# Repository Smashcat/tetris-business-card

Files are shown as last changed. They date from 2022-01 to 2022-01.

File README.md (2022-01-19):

# tetris-business-card
Business card that plays Tetris. Used as xmas toys for clients in 2021!

This repo includes the Eagle design files, production files to use with JLCPCB for full assembly, and firmware to play Tetris and show a couple of animations. All of the parts used here are available on JLC for PCBA, so it should be simple to have them produced and save some soldering! The only thing that might be hard to source at times of the ATMega328pb microcontroller, but it appears from time to time in their stock!

The card is designed for a CR2016 battery. On our cards, we solded a U shaped piece of wire from the pads on each side to hold it in place and keep the card thin enough to go into a wallet. An ideal piece of wire I found was U-shaped sewing pins!

The firmware will compule with Microchip Studio. The card uses pads for tag-connect pogo programmer. I use this cable with an ATMEL ICE programmer, so if you don't have this setup you might want to change this to make it easier to solder wires or something for flashing the firmware. Otherwise maybe flash the firmware on the MCU using an external socket before soldering it on the board.

Although this is kind of specialized for Tetris, I'd be interested in seeing any other games or animations people make!

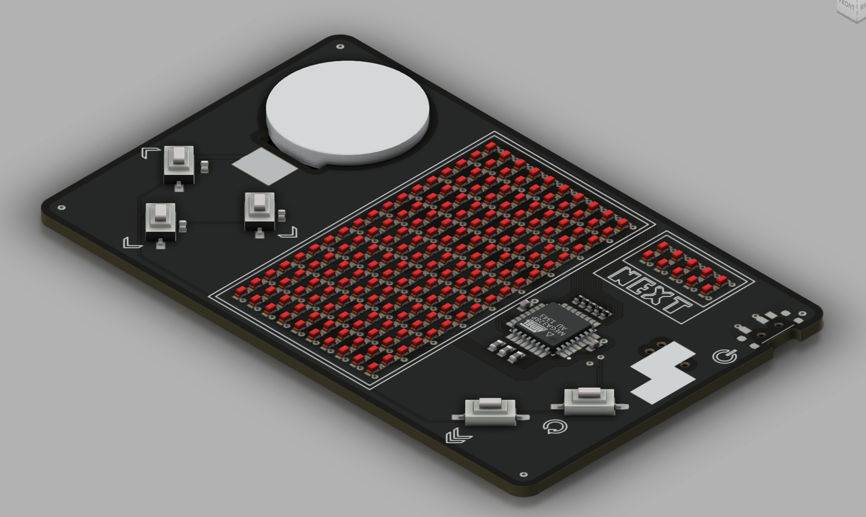
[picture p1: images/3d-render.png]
3D render


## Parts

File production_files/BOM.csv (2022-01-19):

Qty | Designator | Footprint | Comment | LCSC Part # | Description | Device
1 | C2 | C0402 | 0.1uF | C1525 | CAPACITOR, European symbol | C-EUC0402
5 | R5, R9, R10, R12, R14 | R0603 | 10K | C25804 | RESISTOR | 52101-101-REV-A_RC-MASTER-SMD_R_0603MP
1 | C1 | C0402 | 10uf | C15525 | CAPACITOR, European symbol | C-EUC0402
2 | R7, R11 | R0603 | 1K | C21190 | RESISTOR | 52101-101-REV-A_RC-MASTER-SMD_R_0603MP
190 | S_LED1, S_LED2, S_LED3, S_LED4, S_LED5, S_LED6, S_LED7, S_LED8, S_LED9, S_LED10, S_LED11, S_LED12, S_LED13, S_LED14, S_LED15, S_LED16, S_LED17, S_LED18, S_LED19, S_LED20, S_LED21, S_LED22, S_LED23, S_LED24, S_LED25, S_LED26, S_LED27, S_LED28, S_LED29, S_LED30, S_LED31, S_LED32, S_LED33, S_LED34, S_LED35, S_LED36, S_LED37, S_LED38, S_LED39, S_LED40, S_LED41, S_LED42, S_LED43, S_LED44, S_LED45, S_LED46, S_LED47, S_LED48, S_LED49, S_LED50, S_LED51, S_LED52, S_LED53, S_LED54, S_LED55, S_LED56, S_LED57, S_LED58, S_LED59, S_LED60, S_LED61, S_LED62, S_LED63, S_LED64, S_LED65, S_LED66, S_LED67, S_LED68, S_LED69, S_LED70, S_LED71, S_LED72, S_LED73, S_LED74, S_LED75, S_LED76, S_LED77, S_LED78, S_LED79, S_LED80, S_LED81, S_LED82, S_LED83, S_LED84, S_LED85, S_LED86, S_LED87, S_LED88, S_LED89, S_LED90, S_LED91, S_LED92, S_LED93, S_LED94, S_LED95, S_LED96, S_LED97, S_LED98, S_LED99, S_LED100, S_LED101, S_LED102, S_LED103, S_LED104, S_LED105, S_LED106, S_LED107, S_LED108, S_LED109, S_LED110, S_LED111, S_LED112, S_LED113, S_LED114, S_LED115, S_LED116, S_LED117, S_LED118, S_LED119, S_LED120, S_LED121, S_LED122, S_LED123, S_LED124, S_LED125, S_LED126, S_LED127, S_LED128, S_LED129, S_LED130, S_LED131, S_LED132, S_LED133, S_LED134, S_LED135, S_LED136, S_LED137, S_LED138, S_LED139, S_LED140, S_LED141, S_LED142, S_LED143, S_LED144, S_LED145, S_LED146, S_LED147, S_LED148, S_LED149, S_LED150, S_LED151, S_LED152, S_LED153, S_LED154, S_LED155, S_LED156, S_LED157, S_LED158, S_LED159, S_LED160, S_LED1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 | CHIP-LED0603 | 20mA | C375444 | LED | LEDCHIP-LED0603
5 | R1, R2, R3, R8, R15 | R0402 | 470R | C176112 | RESISTOR, European symbol | R-EU_R0402
1 | R6 | R0603 | 4K7 | C23162 | RESISTOR | 52101-101-REV-A_RC-MASTER-SMD_R_0603MP
5 | DOWN, FAST_DROP, LEFT, RIGHT, SPIN | K21107STA4SW06 | K2-1107ST-A4SW-06 | C961737 | Tactile Switches SPST-NO 6.10mm x 3.60mm 2.50mm 50mA @ 12VDC SMD RoHS | K2-1107ST-A4SW-06
1 | S1 | K31296SE1 | K3-1296S-E1 | C431541 | Toggle Switches SMD RoHS | K3-1296S-E1
1 | U1 | MICROCHIP_ATMEGA328PB-AU_0 | MICROCHIP_ATMEGA328PB-AUMICROCHIP_ATMEGA328PB-AU_0_0 | C132230 | ATmega328PB Summary Datasheet | MICROCHIP_ATMEGA328PB-AUMICROCHIP_ATMEGA328PB-AU_0_0

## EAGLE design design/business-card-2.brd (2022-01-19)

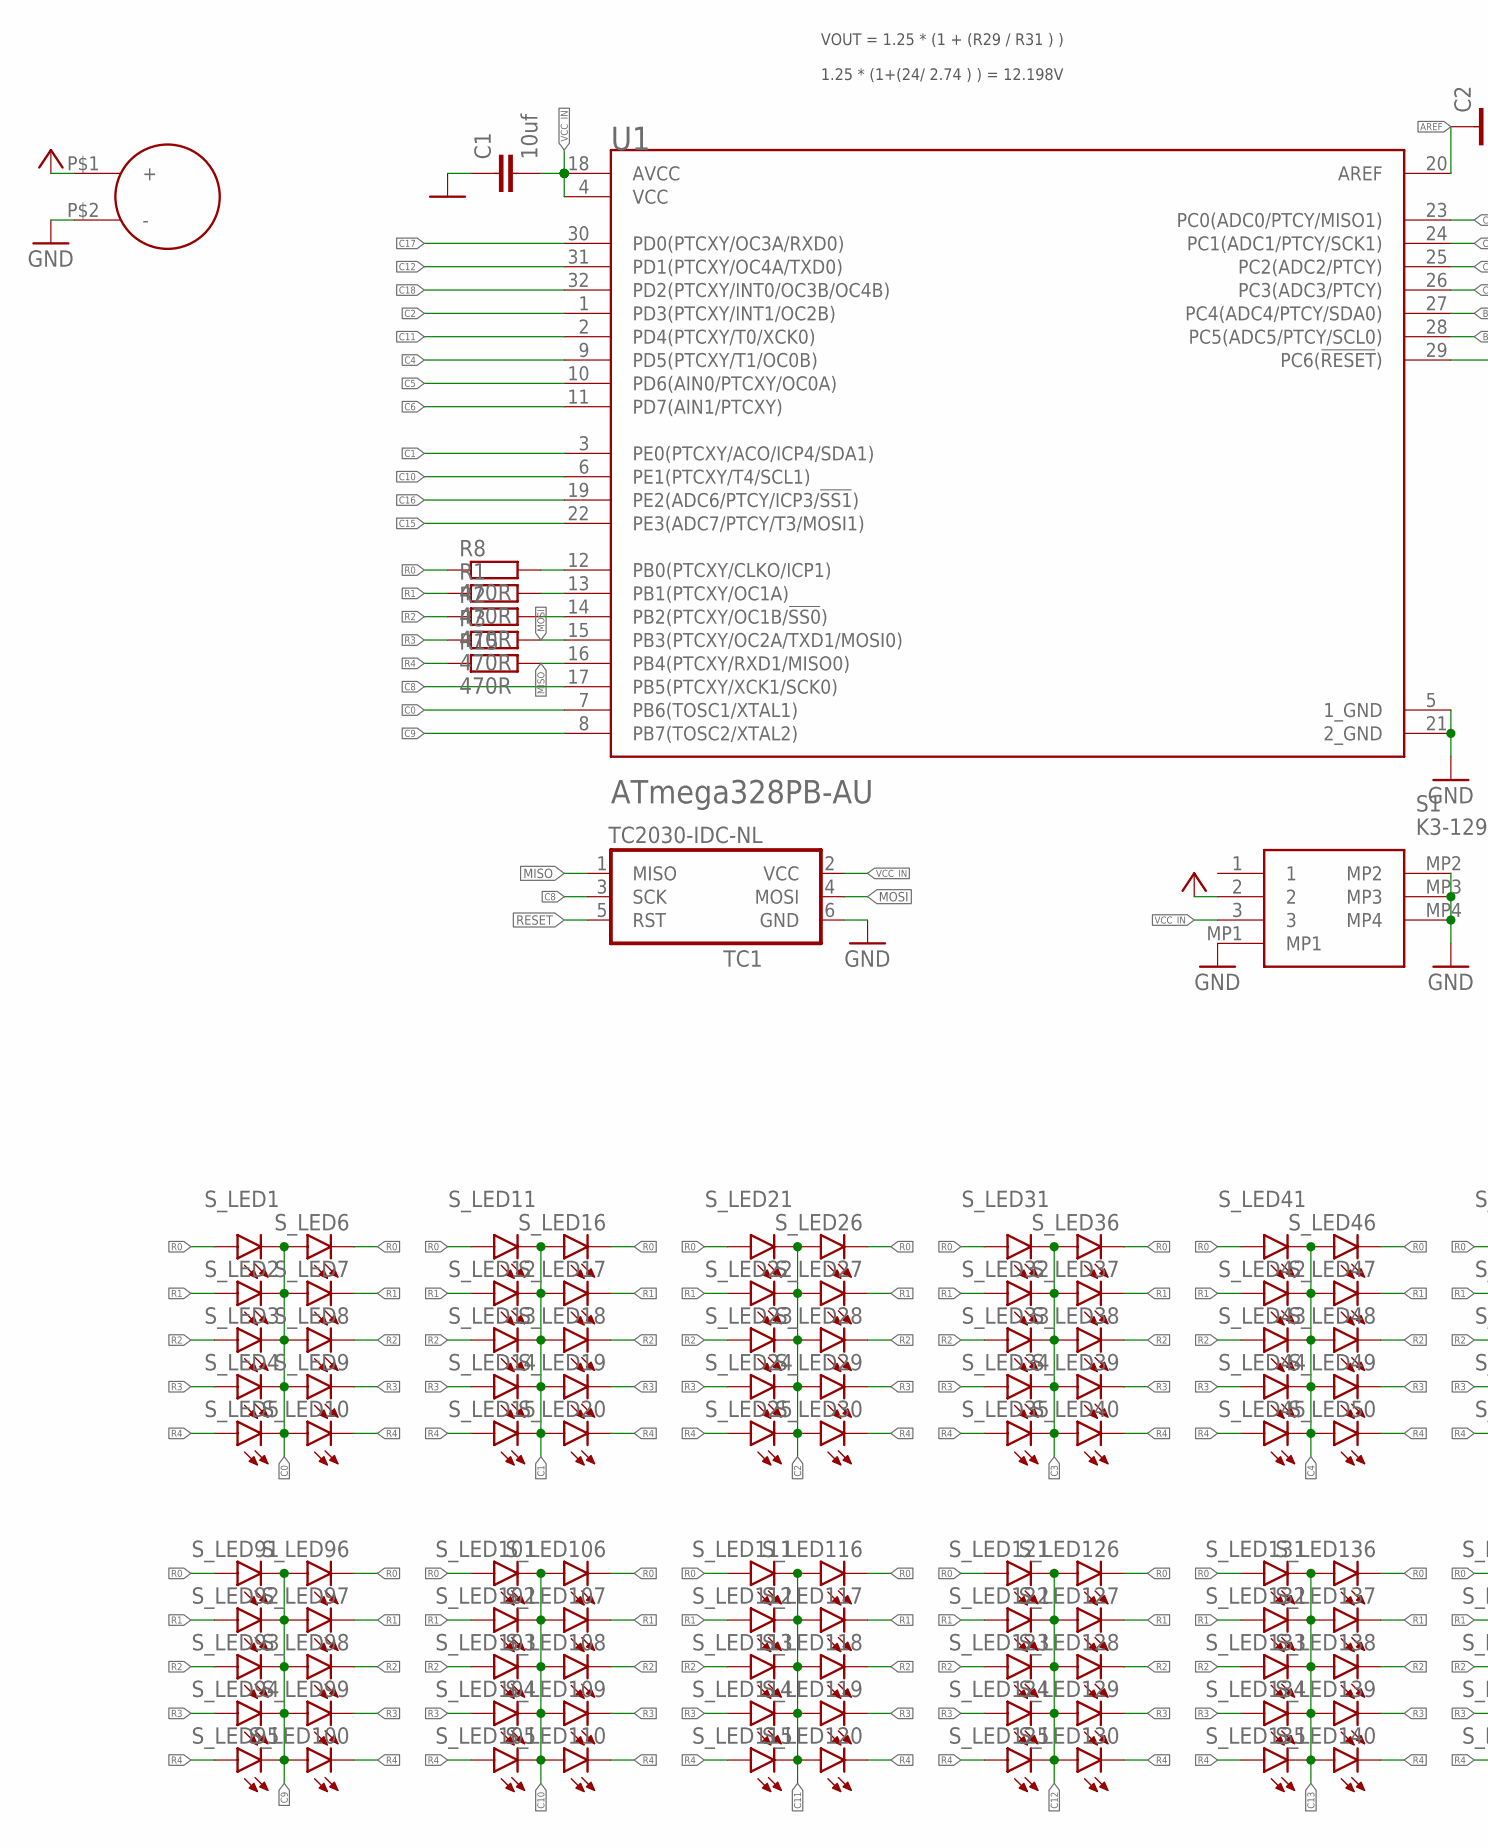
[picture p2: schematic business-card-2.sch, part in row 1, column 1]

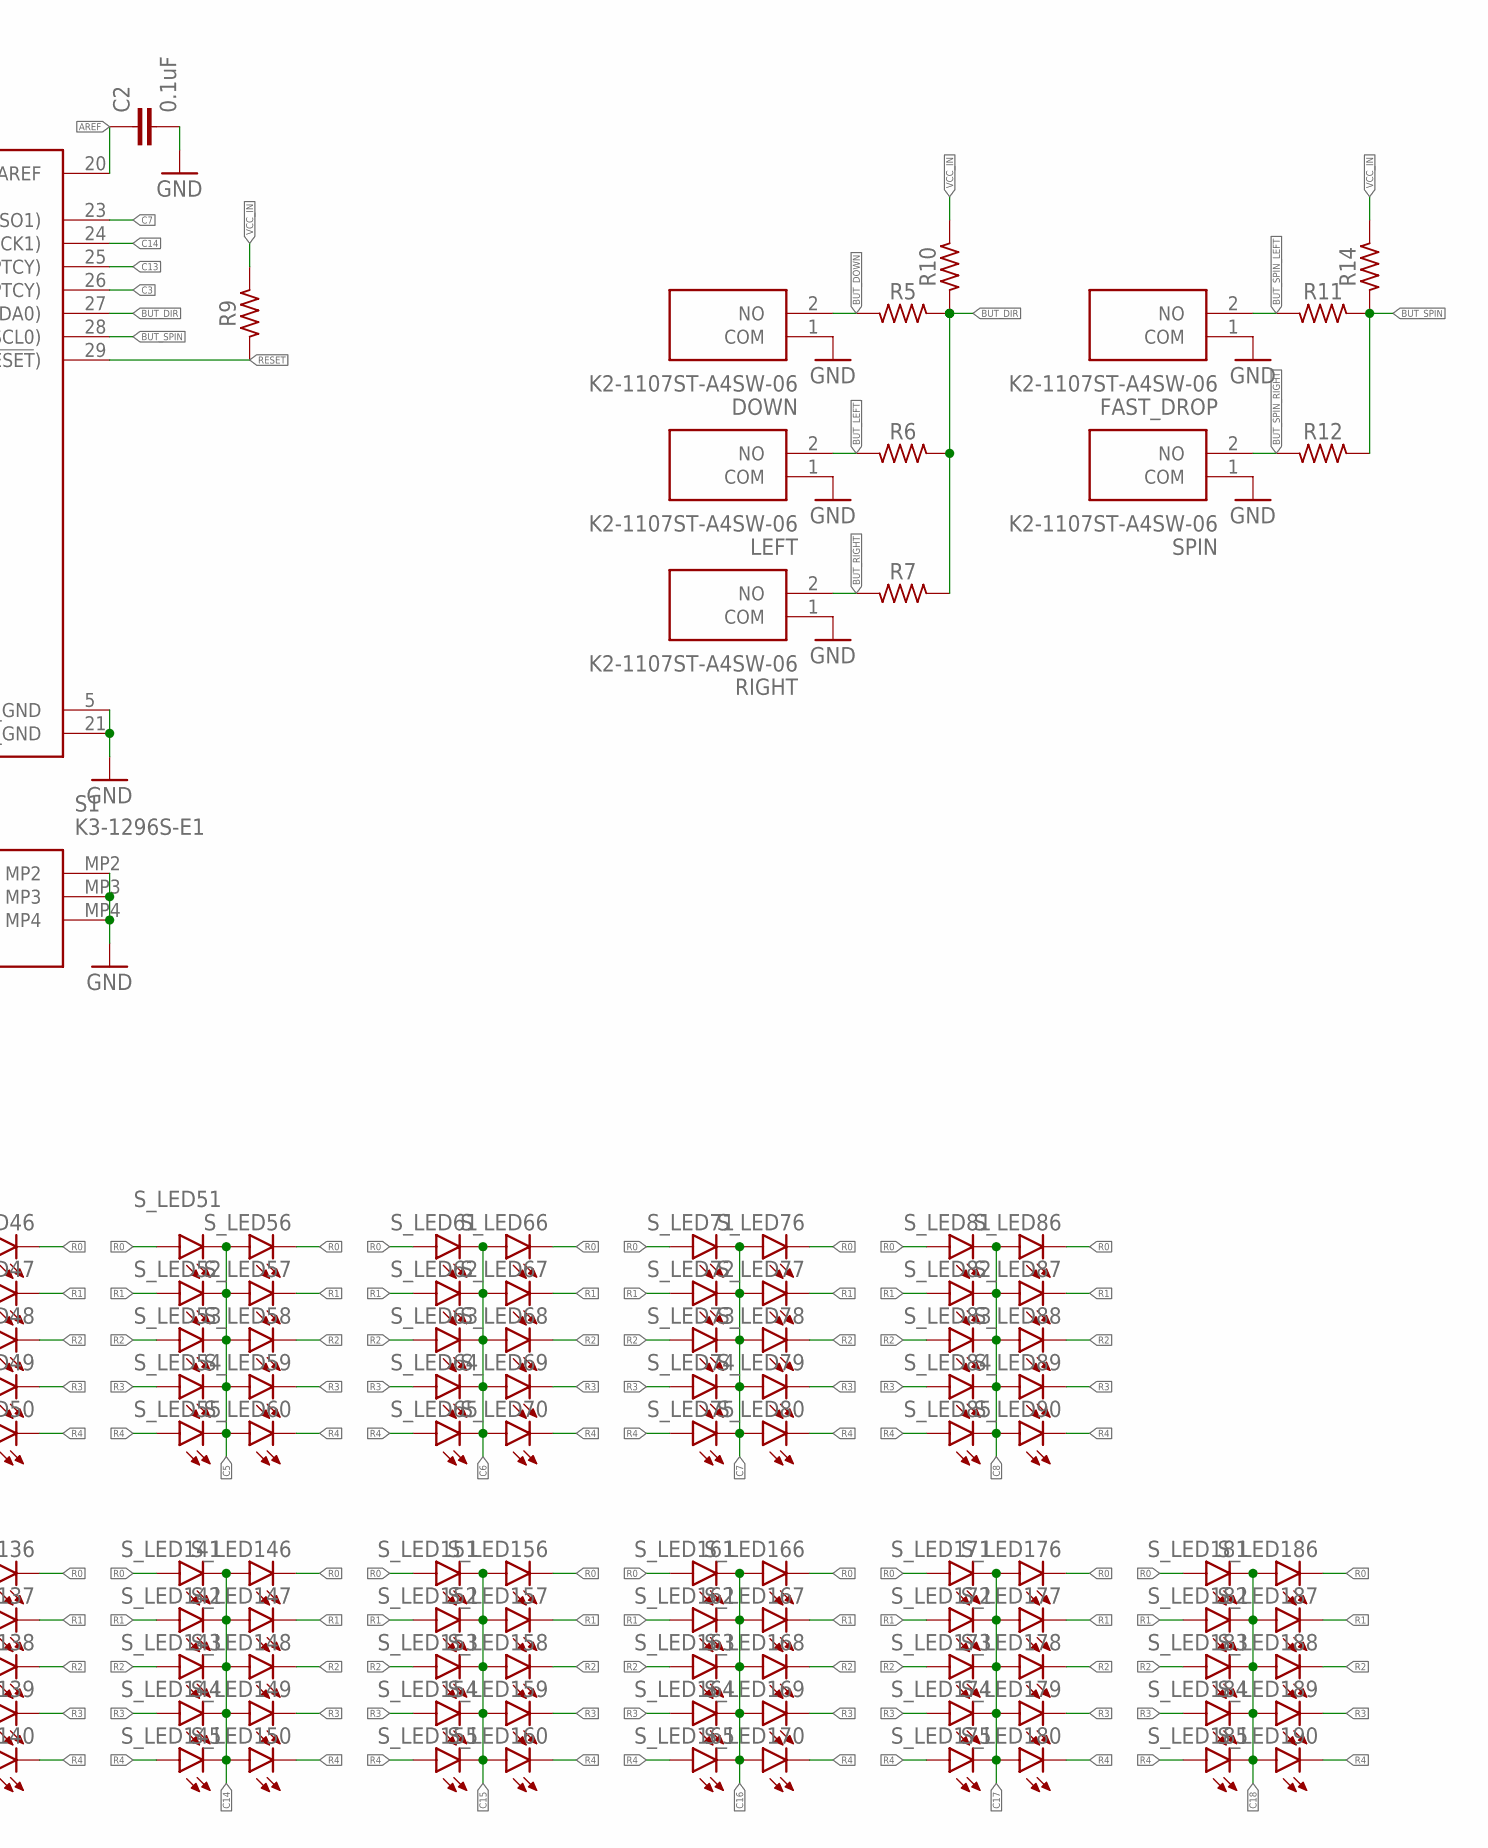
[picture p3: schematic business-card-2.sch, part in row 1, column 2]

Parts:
C1: 10uf; C0402
C2: 0.1uF; C0402
DOWN: K2-1107ST-A4SW-06; K21107STA4SW06
FAST_DROP: K2-1107ST-A4SW-06; K21107STA4SW06
LEFT: K2-1107ST-A4SW-06; K21107STA4SW06
R1, R2, R3, R8, R15: 470R; R0402
R5, R9, R10, R12, R14: 10K; 52101-101-REV-A_RC-MASTER-SMD_R0603MP
R6: 4K7; 52101-101-REV-A_RC-MASTER-SMD_R0603MP
R7, R11: 1K; 52101-101-REV-A_RC-MASTER-SMD_R0603MP
RIGHT: K2-1107ST-A4SW-06; K21107STA4SW06
S1: K3-1296S-E1; K31296SE1
SPIN: K2-1107ST-A4SW-06; K21107STA4SW06
S_LED1, S_LED2, S_LED3, S_LED4, S_LED5, S_LED6, S_LED7, S_LED8, S_LED9, S_LED10, S_LED11, S_LED12, S_LED13, S_LED14, S_LED15, S_LED16, S_LED17, S_LED18, S_LED19, S_LED20, S_LED21, S_LED22, S_LED23, S_LED24, S_LED25, S_LED26, S_LED27, S_LED28, S_LED29, S_LED30, S_LED31, S_LED32, S_LED33, S_LED34, S_LED35, S_LED36, S_LED37, S_LED38, S_LED39, S_LED40, S_LED41, S_LED42, S_LED43, S_LED44, S_LED45, S_LED46, S_LED47, S_LED48, S_LED49, S_LED50, S_LED51, S_LED52, S_LED53, S_LED54, S_LED55, S_LED56, S_LED57, S_LED58, S_LED59, S_LED60, S_LED61, S_LED62, S_LED63, S_LED64, S_LED65, S_LED66, S_LED67, S_LED68, S_LED69, S_LED70, S_LED71, S_LED72, S_LED73, S_LED74, S_LED75, S_LED76, S_LED77, S_LED78, S_LED79, S_LED80, S_LED81, S_LED82, S_LED83, S_LED84, S_LED85, S_LED86, S_LED87, S_LED88, S_LED89, S_LED90, S_LED91, S_LED92, S_LED93, S_LED94, S_LED95, S_LED96, S_LED97, S_LED98, S_LED99, S_LED100, S_LED101, S_LED102, S_LED103, S_LED104, S_LED105, S_LED106, S_LED107, S_LED108, S_LED109, S_LED110, S_LED111, S_LED112, S_LED113, S_LED114, S_LED115, S_LED116, S_LED117, S_LED118, S_LED119, S_LED120, S_LED121, S_LED122, S_LED123, S_LED124, S_LED125, S_LED126, S_LED127, S_LED128, S_LED129, S_LED130, S_LED131, S_LED132, S_LED133, S_LED134, S_LED135, S_LED136, S_LED137, S_LED138, S_LED139, S_LED140, S_LED141, S_LED142, S_LED143, S_LED144, S_LED145, S_LED146, S_LED147, S_LED148, S_LED149, S_LED150, S_LED151, S_LED152, S_LED153, S_LED154, S_LED155, S_LED156, S_LED157, S_LED158, S_LED159, S_LED160, S_LED161, S_LED162, S_LED163, S_LED164, S_LED165, S_LED166, S_LED167, S_LED168, S_LED169, S_LED170, S_LED171, S_LED172, S_LED173, S_LED174, S_LED175, S_LED176, S_LED177, S_LED178, S_LED179, S_LED180, S_LED181, S_LED182, S_LED183, S_LED184, S_LED185, S_LED186, S_LED187, S_LED188, S_LED189, S_LED190: 20mA; CHIP-LED0603
TC1: TC2030-IDC-NL
U1: MICROCHIP_ATMEGA328PB-AUMICROCHIP_ATMEGA328PB-AU_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; MICROCHIP_ATMEGA328PB-AU_0
U$1: THROUGHHOLE-CR2032; THROUGH-HOLE-CR2032

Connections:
AREF: C2.1, U1.20 (AREF)
BUT_DIR: R5.2, R6.2, R7.2, R10.1, U1.27 (PC4(ADC4/PTCY/SDA0))
BUT_DOWN: DOWN.2 (NO), R5.1
BUT_LEFT: LEFT.2 (NO), R6.1
BUT_RIGHT: R7.1, RIGHT.2 (NO)
BUT_SPIN: R11.2, R12.2, R14.1, U1.28 (PC5(ADC5/PTCY/SCL0))
BUT_SPIN_LEFT: FAST_DROP.2 (NO), R11.1
BUT_SPIN_RIGHT: R12.1, SPIN.2 (NO)
C0: S_LED1.C, S_LED2.C, S_LED3.C, S_LED4.C, S_LED5.C, S_LED6.A, S_LED7.A, S_LED8.A, S_LED9.A, S_LED10.A, U1.7 (PB6(TOSC1/XTAL1))
C1: S_LED11.C, S_LED12.C, S_LED13.C, S_LED14.C, S_LED15.C, S_LED16.A, S_LED17.A, S_LED18.A, S_LED19.A, S_LED20.A, U1.3 (PE0(PTCXY/ACO/ICP4/SDA1))
C2: S_LED21.C, S_LED22.C, S_LED23.C, S_LED24.C, S_LED25.C, S_LED26.A, S_LED27.A, S_LED28.A, S_LED29.A, S_LED30.A, U1.1 (PD3(PTCXY/INT1/OC2B))
C3: S_LED31.C, S_LED32.C, S_LED33.C, S_LED34.C, S_LED35.C, S_LED36.A, S_LED37.A, S_LED38.A, S_LED39.A, S_LED40.A, U1.26 (PC3(ADC3/PTCY))
C4: S_LED41.C, S_LED42.C, S_LED43.C, S_LED44.C, S_LED45.C, S_LED46.A, S_LED47.A, S_LED48.A, S_LED49.A, S_LED50.A, U1.9 (PD5(PTCXY/T1/OC0B))
C5: S_LED51.C, S_LED52.C, S_LED53.C, S_LED54.C, S_LED55.C, S_LED56.A, S_LED57.A, S_LED58.A, S_LED59.A, S_LED60.A, U1.10 (PD6(AIN0/PTCXY/OC0A))
C6: S_LED61.C, S_LED62.C, S_LED63.C, S_LED64.C, S_LED65.C, S_LED66.A, S_LED67.A, S_LED68.A, S_LED69.A, S_LED70.A, U1.11 (PD7(AIN1/PTCXY))
C7: S_LED71.C, S_LED72.C, S_LED73.C, S_LED74.C, S_LED75.C, S_LED76.A, S_LED77.A, S_LED78.A, S_LED79.A, S_LED80.A, U1.23 (PC0(ADC0/PTCY/MISO1))
C8: S_LED81.C, S_LED82.C, S_LED83.C, S_LED84.C, S_LED85.C, S_LED86.A, S_LED87.A, S_LED88.A, S_LED89.A, S_LED90.A, TC1.3 (SCK), U1.17 (PB5(PTCXY/XCK1/SCK0))
C9: S_LED91.C, S_LED92.C, S_LED93.C, S_LED94.C, S_LED95.C, S_LED96.A, S_LED97.A, S_LED98.A, S_LED99.A, S_LED100.A, U1.8 (PB7(TOSC2/XTAL2))
C10: S_LED101.C, S_LED102.C, S_LED103.C, S_LED104.C, S_LED105.C, S_LED106.A, S_LED107.A, S_LED108.A, S_LED109.A, S_LED110.A, U1.6 (PE1(PTCXY/T4/SCL1))
C11: S_LED111.C, S_LED112.C, S_LED113.C, S_LED114.C, S_LED115.C, S_LED116.A, S_LED117.A, S_LED118.A, S_LED119.A, S_LED120.A, U1.2 (PD4(PTCXY/T0/XCK0))
C12: S_LED121.C, S_LED122.C, S_LED123.C, S_LED124.C, S_LED125.C, S_LED126.A, S_LED127.A, S_LED128.A, S_LED129.A, S_LED130.A, U1.31 (PD1(PTCXY/OC4A/TXD0))
C13: S_LED131.C, S_LED132.C, S_LED133.C, S_LED134.C, S_LED135.C, S_LED136.A, S_LED137.A, S_LED138.A, S_LED139.A, S_LED140.A, U1.25 (PC2(ADC2/PTCY))
C14: S_LED141.C, S_LED142.C, S_LED143.C, S_LED144.C, S_LED145.C, S_LED146.A, S_LED147.A, S_LED148.A, S_LED149.A, S_LED150.A, U1.24 (PC1(ADC1/PTCY/SCK1))
C15: S_LED151.C, S_LED152.C, S_LED153.C, S_LED154.C, S_LED155.C, S_LED156.A, S_LED157.A, S_LED158.A, S_LED159.A, S_LED160.A, U1.22 (PE3(ADC7/PTCY/T3/MOSI1))
C16: S_LED161.C, S_LED162.C, S_LED163.C, S_LED164.C, S_LED165.C, S_LED166.A, S_LED167.A, S_LED168.A, S_LED169.A, S_LED170.A, U1.19 (PE2(ADC6/PTCY/ICP3/!SS1!))
C17: S_LED171.C, S_LED172.C, S_LED173.C, S_LED174.C, S_LED175.C, S_LED176.A, S_LED177.A, S_LED178.A, S_LED179.A, S_LED180.A, U1.30 (PD0(PTCXY/OC3A/RXD0))
C18: S_LED181.C, S_LED182.C, S_LED183.C, S_LED184.C, S_LED185.C, S_LED186.A, S_LED187.A, S_LED188.A, S_LED189.A, S_LED190.A, U1.32 (PD2(PTCXY/INT0/OC3B/OC4B))
GND: C1.1, C2.2, DOWN.1 (COM), FAST_DROP.1 (COM), LEFT.1 (COM), RIGHT.1 (COM), S1.MP1, S1.MP2, S1.MP3, S1.MP4, SPIN.1 (COM), TC1.6 (GND), U1.5 (1_GND), U1.21 (2_GND), U$1.P$2 (-)
MISO: R15.2, TC1.1 (MISO), U1.16 (PB4(PTCXY/RXD1/MISO0))
MOSI: R3.2, TC1.4 (MOSI), U1.15 (PB3(PTCXY/OC2A/TXD1/MOSI0))
unnamed: R2.2, U1.14 (PB2(PTCXY/OC1B/!SS0!))
unnamed: R8.2, U1.12 (PB0(PTCXY/CLKO/ICP1))
unnamed: R1.2, U1.13 (PB1(PTCXY/OC1A))
R0: R8.1, S_LED1.A, S_LED6.C, S_LED11.A, S_LED16.C, S_LED21.A, S_LED26.C, S_LED31.A, S_LED36.C, S_LED41.A, S_LED46.C, S_LED51.A, S_LED56.C, S_LED61.A, S_LED66.C, S_LED71.A, S_LED76.C, S_LED81.A, S_LED86.C, S_LED91.A, S_LED96.C, S_LED101.A, S_LED106.C, S_LED111.A, S_LED116.C, S_LED121.A, S_LED126.C, S_LED131.A, S_LED136.C, S_LED141.A, S_LED146.C, S_LED151.A, S_LED156.C, S_LED161.A, S_LED166.C, S_LED171.A, S_LED176.C, S_LED181.A, S_LED186.C
R1: R1.1, S_LED2.A, S_LED7.C, S_LED12.A, S_LED17.C, S_LED22.A, S_LED27.C, S_LED32.A, S_LED37.C, S_LED42.A, S_LED47.C, S_LED52.A, S_LED57.C, S_LED62.A, S_LED67.C, S_LED72.A, S_LED77.C, S_LED82.A, S_LED87.C, S_LED92.A, S_LED97.C, S_LED102.A, S_LED107.C, S_LED112.A, S_LED117.C, S_LED122.A, S_LED127.C, S_LED132.A, S_LED137.C, S_LED142.A, S_LED147.C, S_LED152.A, S_LED157.C, S_LED162.A, S_LED167.C, S_LED172.A, S_LED177.C, S_LED182.A, S_LED187.C
R2: R2.1, S_LED3.A, S_LED8.C, S_LED13.A, S_LED18.C, S_LED23.A, S_LED28.C, S_LED33.A, S_LED38.C, S_LED43.A, S_LED48.C, S_LED53.A, S_LED58.C, S_LED63.A, S_LED68.C, S_LED73.A, S_LED78.C, S_LED83.A, S_LED88.C, S_LED93.A, S_LED98.C, S_LED103.A, S_LED108.C, S_LED113.A, S_LED118.C, S_LED123.A, S_LED128.C, S_LED133.A, S_LED138.C, S_LED143.A, S_LED148.C, S_LED153.A, S_LED158.C, S_LED163.A, S_LED168.C, S_LED173.A, S_LED178.C, S_LED183.A, S_LED188.C
R3: R3.1, S_LED4.A, S_LED9.C, S_LED14.A, S_LED19.C, S_LED24.A, S_LED29.C, S_LED34.A, S_LED39.C, S_LED44.A, S_LED49.C, S_LED54.A, S_LED59.C, S_LED64.A, S_LED69.C, S_LED74.A, S_LED79.C, S_LED84.A, S_LED89.C, S_LED94.A, S_LED99.C, S_LED104.A, S_LED109.C, S_LED114.A, S_LED119.C, S_LED124.A, S_LED129.C, S_LED134.A, S_LED139.C, S_LED144.A, S_LED149.C, S_LED154.A, S_LED159.C, S_LED164.A, S_LED169.C, S_LED174.A, S_LED179.C, S_LED184.A, S_LED189.C
R4: R15.1, S_LED5.A, S_LED10.C, S_LED15.A, S_LED20.C, S_LED25.A, S_LED30.C, S_LED35.A, S_LED40.C, S_LED45.A, S_LED50.C, S_LED55.A, S_LED60.C, S_LED65.A, S_LED70.C, S_LED75.A, S_LED80.C, S_LED85.A, S_LED90.C, S_LED95.A, S_LED100.C, S_LED105.A, S_LED110.C, S_LED115.A, S_LED120.C, S_LED125.A, S_LED130.C, S_LED135.A, S_LED140.C, S_LED145.A, S_LED150.C, S_LED155.A, S_LED160.C, S_LED165.A, S_LED170.C, S_LED175.A, S_LED180.C, S_LED185.A, S_LED190.C
RESET: R9.1, TC1.5 (RST), U1.29 (PC6(!RESET!))
VCC: S1.2, U$1.P$1 (+)
VCC_IN: C1.2, R9.2, R10.2, R14.2, S1.3, TC1.2 (VCC), U1.4 (VCC), U1.18 (AVCC)

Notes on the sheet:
VOUT = 1.25 * (1 + (R29 / R31 ) ) 1.25 * (1+(24/ 2.74 ) ) = 12.198V

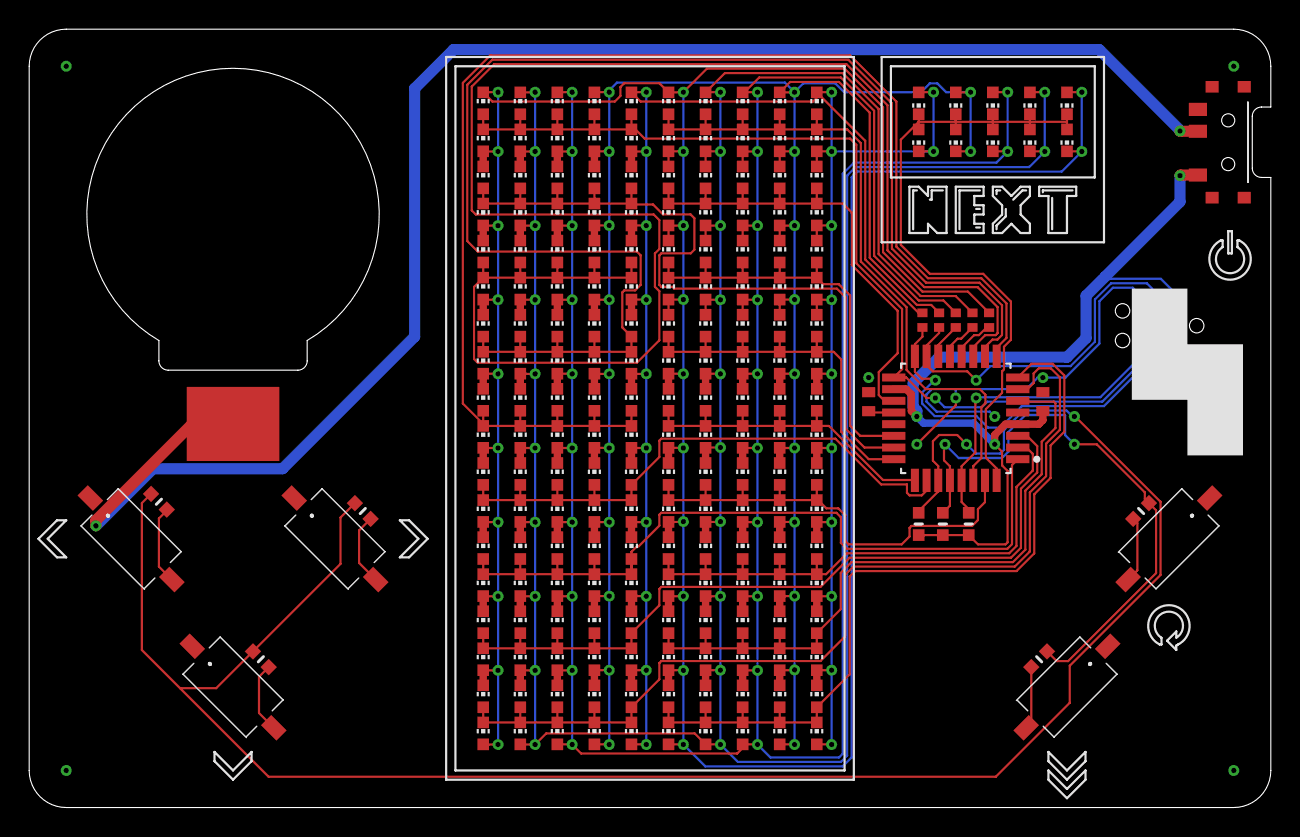
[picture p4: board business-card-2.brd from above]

Board: 2 copper layers, 85.1 x 53.3 mm, 214 parts (1 on the bottom side), 41 nets.

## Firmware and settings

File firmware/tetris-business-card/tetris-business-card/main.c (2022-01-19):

/*
 * tetris-business-card.c
 *
 * Created: 10/09/2021 13:37:38
 * Author : Scott Porter
 */ 

#include "funcs.h"
#include "tetris.h"
#include "maze.h"
#include "life.h"

int main(void)
{
	while(1){
		
		// Version 1 boards had hardware interrupt to wake from sleep. New boards use slide switch.
		#if VER==1
		goToSleep();
		#endif

		setup();
		//testButtons();	// Enable this to just test the input buttons
		#if VER==2
		getButtonState();
		#endif
		//testDisplay();	// enable this to just test the LED matrix
		if(butPressed(BUTTON_LEFT)){
			waitBut();
			spinCog();
			playGameOfLife();
		}
		doMenu();
		playTetris();
		/* Initially was going to have 2 games. But ran out of time!
		uint8_t option=doMenu();
		switch(option){
			case 0:
				playTetris();
				break;
			case 1:
				playMaze();
				break;
			default:
				break;
		}
		*/
		shutdown();
		spinLogo();
	}
}

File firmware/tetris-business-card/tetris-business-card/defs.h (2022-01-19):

/*
 * defs.h
 *
 * Created: 10/09/2021 13:44:23
 *  Author: Scott Porter
 */ 


#ifndef DEFS_H_
#define DEFS_H_

// Version 1 boards used a wake button, version 2 uses a slide switch for power-on/off
#define VER					2

// If in test mode, preload game grid ready for a tetris
#define TEST_MODE			0

// Defines used to switch display between fast and slow modes
#define VIDEO_MODE_FAST		1
#define VIDEO_MODE_SLOW		2

// Number of bytes per video frame (3 brightness levels per pixel)
#define BYTES_PER_FRAME		45

// Speed at which to update the "next piece" display. Lower=faster
#define NP_SPEED			2

// The game speeds up every 2 rows cleared
// Initial game speed - higher = slower
#define INITIAL_GAME_SPEED	30

// Highest game speed - lower = faster - 5 is about the limit of playability
#define HIGHEST_GAME_SPEED	5

// Speed of the timer interrupt that runs the LEDs - lower = faster, but this will slow the rest of the code
#define TIMER_SPEED_SLOW	28

// Speed for "fast" mode, where the LEDs are only 1 brightness, so can spend
// less time in the display update interrupt, leaving more cycles for other processing
#define TIMER_SPEED_FAST	100

// Delay per frame used when scrolling score/hiscore
#define SHOW_SCORE_DELAY	7

// Delay per frame used when scrolling intro
#define INTRO_DELAY			1

// Delay per frame when clearing blocks
#define CLEAR_DELAY			4

// Delay per frame when scrolling blocks down screen at game over
#define GAME_OVER_DELAY		3

// Number of columns in LED array (including "next piece" area)
#define MAX_COL				38

// Number of columns in main LED array (display is 36 columns of 5 LEDs)
#define MAIN_MAX_COL		36

// Pin definitions for button inputs - pin 2 is a hardware interrupt to wake/sleep, the other 2 are on the ADC, to handle multiple buttons
#define BUT_ON_OFF	2
#define BUT_DIR		4
#define BUT_SPIN	5

// Positions for button states in bitfield
#define BUTTON_FAST_DROP	0
#define BUTTON_SPIN			1
#define BUTTON_LEFT			2
#define BUTTON_RIGHT		3
#define BUTTON_DOWN			4
#define BUTTON_ON_OFF		5

// 7 displayed shapes in Tetris game
#define TOTAL_SHAPES		7
#define TOTAL_ROTATIONS		4
#define TOTAL_COORDINATES	4

// Game states
#define STATE_IDLE			0
#define STATE_PLAYING		1
#define STATE_FAST_DROP		2
#define STATE_LANDED		3
#define STATE_CLEARING_ROW	4
#define STATE_GAMEOVER		5

// Signature byte compared to this to check if EEPROM initialized
#define EEPROM_SIG			10

#if VER==1
#define FAST_DROP_ADC		4
#define SPIN_ADC			10
#define DOWN_ADC			10
#define LEFT_ADC			14
#define RIGHT_ADC			15
#elif VER==2
#define FAST_DROP_ADC		4
#define SPIN_ADC			10
#define DOWN_ADC			10
#define LEFT_ADC			7
#define RIGHT_ADC			3
#endif

#endif /* DEFS_H_ */

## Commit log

2022-01-19 Added design and production files
    [BOM.csv, business-card-2.brd, business-card-2.sch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]
2022-01-19 Removed tmp files
    [business-card-2.brd]
